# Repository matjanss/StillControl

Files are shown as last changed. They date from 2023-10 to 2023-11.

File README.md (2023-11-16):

# StillControl
Simple Arduino Nano based solid state relay control hardware and software



Repository will be updated intermittently.

Please refer to the "Hardware" folder for the PCB & license information, software folder contains a VSCode project.

https://youtu.be/iHSRMQVA5wc

Watch the video (https://youtu.be/iHSRMQVA5wc)

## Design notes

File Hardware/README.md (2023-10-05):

# StillControl PCB v1.0
Simple Arduino Nano based solid state relay control hardware and software

---

The PCB is a relatively simple breakout board for an Arduino Nano, exposing a number of interfaces in JST PH (2.00mm) connectors and standard 2.54mm pin Headers:

- Footprint for an Arduino Nano V3 with (optional/additional) breakout pin row exposed.
- 3 potentiometers (with filter caps & resistor)
- 3 buffered and somewhat protected SSR outputs
- I2C for ie. display or other peripherals
- I2C header for a BMP388/390 barometer
- 1-Wire interface for temperature sensors
- Buzzer
- Error led connector
- On board 5V regulator, needs 9-12V

WhatsApp Image 2023-10-05 at 22 21 52

Repository will be updated when board is tested, updates to be done in v1.1
Hardware is licensed under Creative Commons NC BY SA.

JLCPCB Production files: StillSSR-Arduinonano.zip

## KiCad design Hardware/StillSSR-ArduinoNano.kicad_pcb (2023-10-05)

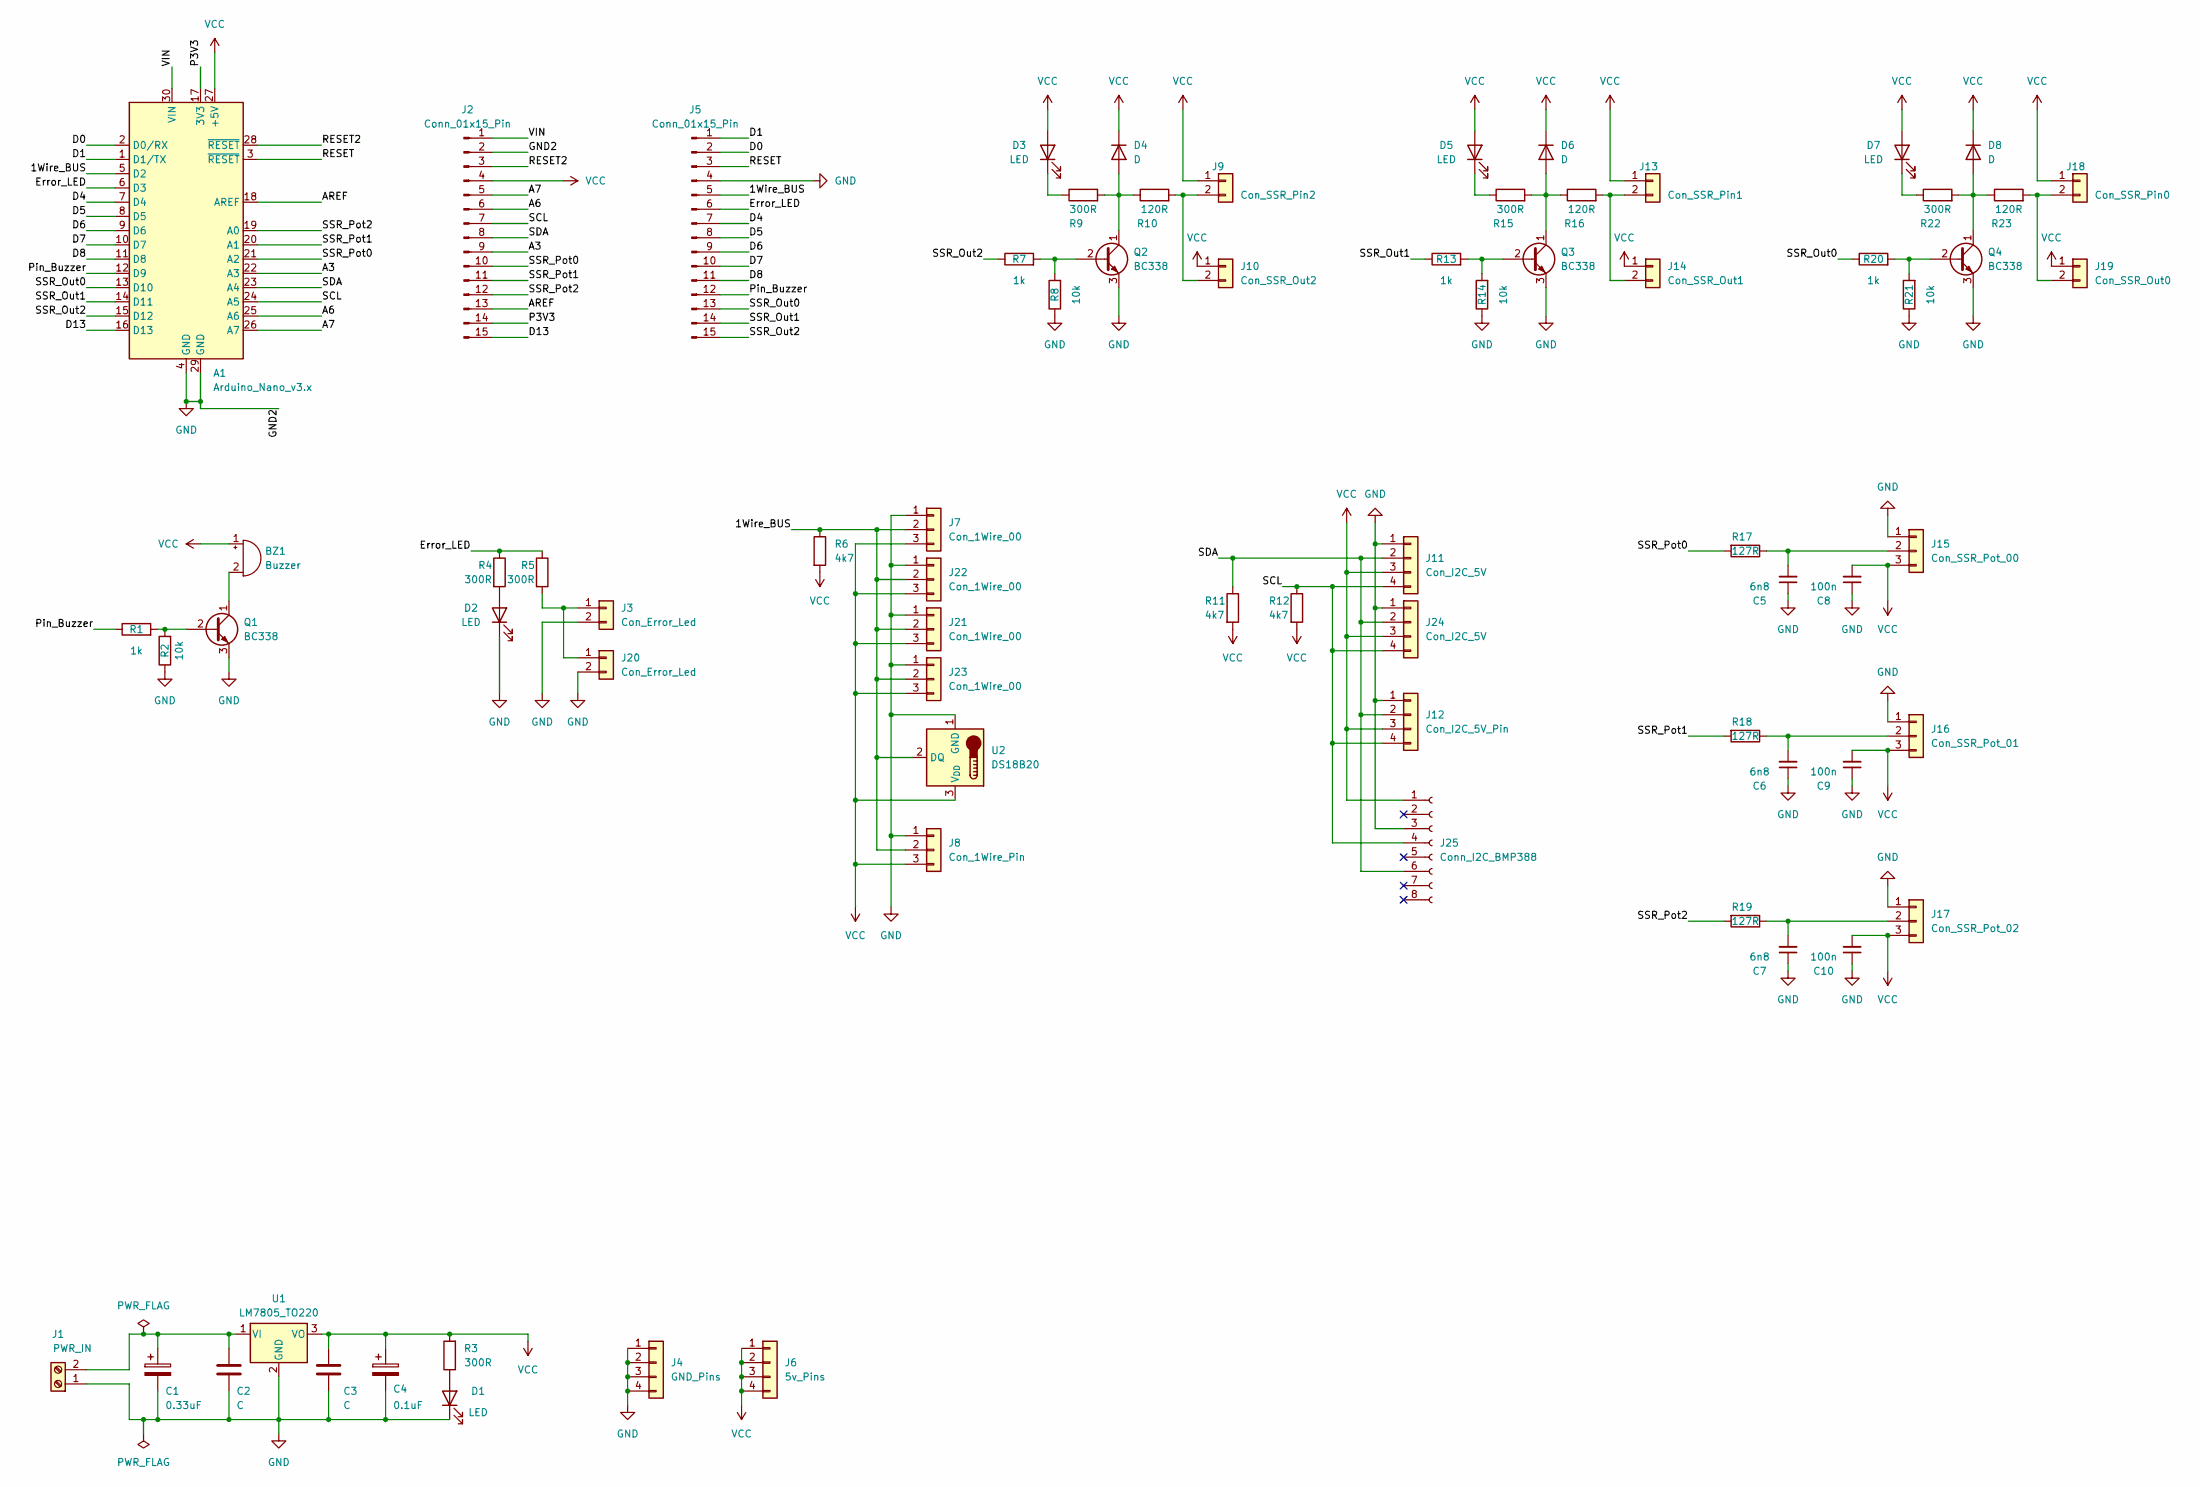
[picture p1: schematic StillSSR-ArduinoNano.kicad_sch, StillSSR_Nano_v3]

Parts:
A1: Arduino_Nano_v3.x; Arduino_Nano
BZ1: Buzzer; Buzzer_12x9.5RM7.6
C1: 0.33uF; CP_Radial_D5.0mm_P2.50mm
C2, C3: C; C_Rect_L4.0mm_W2.5mm_P2.50mm
C4: 0.1uF; CP_Radial_D5.0mm_P2.50mm
C5, C6, C7: 6n8; C_Rect_L4.0mm_W2.5mm_P2.50mm
C8, C9, C10: 100n; C_Rect_L4.0mm_W2.5mm_P2.50mm
D1, D2, D3, D5, D7: LED; LED_D3.0mm
D4, D6, D8: D; D_DO-34_SOD68_P7.62mm_Horizontal
J1: PWR_IN; TerminalBlock_bornier-2_P5.08mm
J2, J5: Conn_01x15_Pin; PinSocket_1x15_P2.54mm_Vertical
J3: Con_Error_Led; JST_PH_B2B-PH-K_1x02_P2.00mm_Vertical
J4: GND_Pins; PinHeader_1x04_P2.54mm_Vertical
J6: 5v_Pins; PinHeader_1x04_P2.54mm_Vertical
J7, J21, J22, J23: Con_1Wire_00; JST_PH_B3B-PH-K_1x03_P2.00mm_Vertical
J8: Con_1Wire_Pin; PinHeader_1x03_P2.54mm_Vertical
J9: Con_SSR_Pin2; PinHeader_1x02_P2.54mm_Vertical
J10: Con_SSR_Out2; JST_PH_B2B-PH-K_1x02_P2.00mm_Vertical
J11, J24: Con_I2C_5V; JST_PH_B4B-PH-K_1x04_P2.00mm_Vertical
J12: Con_I2C_5V_Pin; PinHeader_1x04_P2.54mm_Vertical
J13: Con_SSR_Pin1; PinHeader_1x02_P2.54mm_Vertical
J14: Con_SSR_Out1; JST_PH_B2B-PH-K_1x02_P2.00mm_Vertical
J15: Con_SSR_Pot_00; JST_PH_B3B-PH-K_1x03_P2.00mm_Vertical
J16: Con_SSR_Pot_01; JST_PH_B3B-PH-K_1x03_P2.00mm_Vertical
J17: Con_SSR_Pot_02; JST_PH_B3B-PH-K_1x03_P2.00mm_Vertical
J18: Con_SSR_Pin0; PinHeader_1x02_P2.54mm_Vertical
J19: Con_SSR_Out0; JST_PH_B2B-PH-K_1x02_P2.00mm_Vertical
J20: Con_Error_Led; PinHeader_1x02_P2.54mm_Vertical
J25: Conn_I2C_BMP388; PinSocket_1x08_P2.54mm_Vertical
Q1, Q2, Q3, Q4: BC338; TO-92_Inline
R1, R7, R13, R20: 1k; R_Axial_DIN0207_L6.3mm_D2.5mm_P7.62mm_Horizontal
R2, R8, R14, R21: 10k; R_Axial_DIN0207_L6.3mm_D2.5mm_P7.62mm_Horizontal
R3, R4, R5, R9, R15, R22: 300R; R_Axial_DIN0207_L6.3mm_D2.5mm_P7.62mm_Horizontal
R6, R11, R12: 4k7; R_Axial_DIN0207_L6.3mm_D2.5mm_P7.62mm_Horizontal
R10, R16, R23: 120R; R_Axial_DIN0207_L6.3mm_D2.5mm_P7.62mm_Horizontal
R17, R18, R19: 127R; R_Axial_DIN0207_L6.3mm_D2.5mm_P7.62mm_Horizontal
U1: LM7805_TO220; TO-220-3_Vertical
U2: DS18B20; TO-92_Inline

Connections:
/1Wire_BUS: A1.5 (D2), J5.5, J7.2, J8.2, J21.2, J22.2, J23.2, R6.1, U2.2 (DQ)
/A3: A1.22 (A3), J2.9
/A6: A1.25 (A6), J2.6
/A7: A1.26 (A7), J2.5
/AREF: A1.18 (AREF), J2.13
/D0: A1.2 (D0/RX), J5.2
/D1: A1.1 (D1/TX), J5.1
/D4: A1.7 (D4), J5.7
/D5: A1.8 (D5), J5.8
/D6: A1.9 (D6), J5.9
/D7: A1.10 (D7), J5.10
/D8: A1.11 (D8), J5.11
/D13: A1.16 (D13), J2.15
/Error_LED: A1.6 (D3), J5.6, R4.1, R5.1
/P3V3: A1.17 (3V3), J2.14
/Pin_Buzzer: A1.12 (D9), J5.12, R1.1
/RESET: A1.3 (~RESET), J5.3
/RESET2: A1.28 (~RESET), J2.3
/SCL: A1.24 (A5), J2.7, J11.4, J12.4, J24.4, J25.4, R12.1
/SDA: A1.23 (A4), J2.8, J11.2, J12.2, J24.2, J25.6, R11.1
/SSR_Out0: A1.13 (D10), J5.13, R20.1
/SSR_Out1: A1.14 (D11), J5.14, R13.1
/SSR_Out2: A1.15 (D12), J5.15, R7.1
/SSR_Pot0: A1.21 (A2), J2.10, R17.2
/SSR_Pot1: A1.20 (A1), J2.11, R18.2
/SSR_Pot2: A1.19 (A0), J2.12, R19.2
/VIN: A1.30 (VIN), J2.1
GND: A1.4 (GND), A1.29 (GND), C1.2, C2.2, C3.2, C4.2, C5.1, C6.1, C7.1, C8.1, C9.1, C10.1, D1.1 (K), D2.1 (K), J1.1, J2.2, J3.2, J4.1, J4.2, J4.3, J4.4, J5.4, J7.1, J8.1, J11.1, J12.1, J15.1, J16.1, J17.1, J20.2, J21.1, J22.1, J23.1, J24.1, J25.3, Q1.3 (E), Q2.3 (E), Q3.3 (E), Q4.3 (E), R2.1, R8.1, R14.1, R21.1, U1.2 (GND), U2.1 (GND)
unnamed: BZ1.2 (+), Q1.1 (C)
unnamed: D1.2 (A), R3.1
unnamed: D2.2 (A), R4.2
unnamed: D3.1 (K), R9.1
unnamed: D4.2 (A), Q2.1 (C), R9.2, R10.1
unnamed: D5.1 (K), R15.1
unnamed: D6.2 (A), Q3.1 (C), R15.2, R16.1
unnamed: D7.1 (K), R22.1
unnamed: D8.2 (A), Q4.1 (C), R22.2, R23.1
unnamed: C1.1, C2.1, J1.2, U1.1 (VI)
unnamed: J9.2, J10.2, R10.2
unnamed: J13.2, J14.2, R16.2
unnamed: C5.2, J15.2, R17.1
unnamed: C6.2, J16.2, R18.1
unnamed: C7.2, J17.2, R19.1
unnamed: J18.2, J19.2, R23.2
unnamed: J3.1, J20.1, R5.2
unnamed: Q1.2 (B), R1.2, R2.2
unnamed: Q2.2 (B), R7.2, R8.2
unnamed: Q3.2 (B), R13.2, R14.2
unnamed: Q4.2 (B), R20.2, R21.2
VCC: A1.27 (+5V), BZ1.1 (-), C3.1, C4.1, C8.2, C9.2, C10.2, D3.2 (A), D4.1 (K), D5.2 (A), D6.1 (K), D7.2 (A), D8.1 (K), J2.4, J6.1, J6.2, J6.3, J6.4, J7.3, J8.3, J9.1, J10.1, J11.3, J12.3, J13.1, J14.1, J15.3, J16.3, J17.3, J18.1, J19.1, J21.3, J22.3, J23.3, J24.3, J25.1, R3.2, R6.2, R11.2, R12.2, U1.3 (VO), U2.3 (V_{DD})

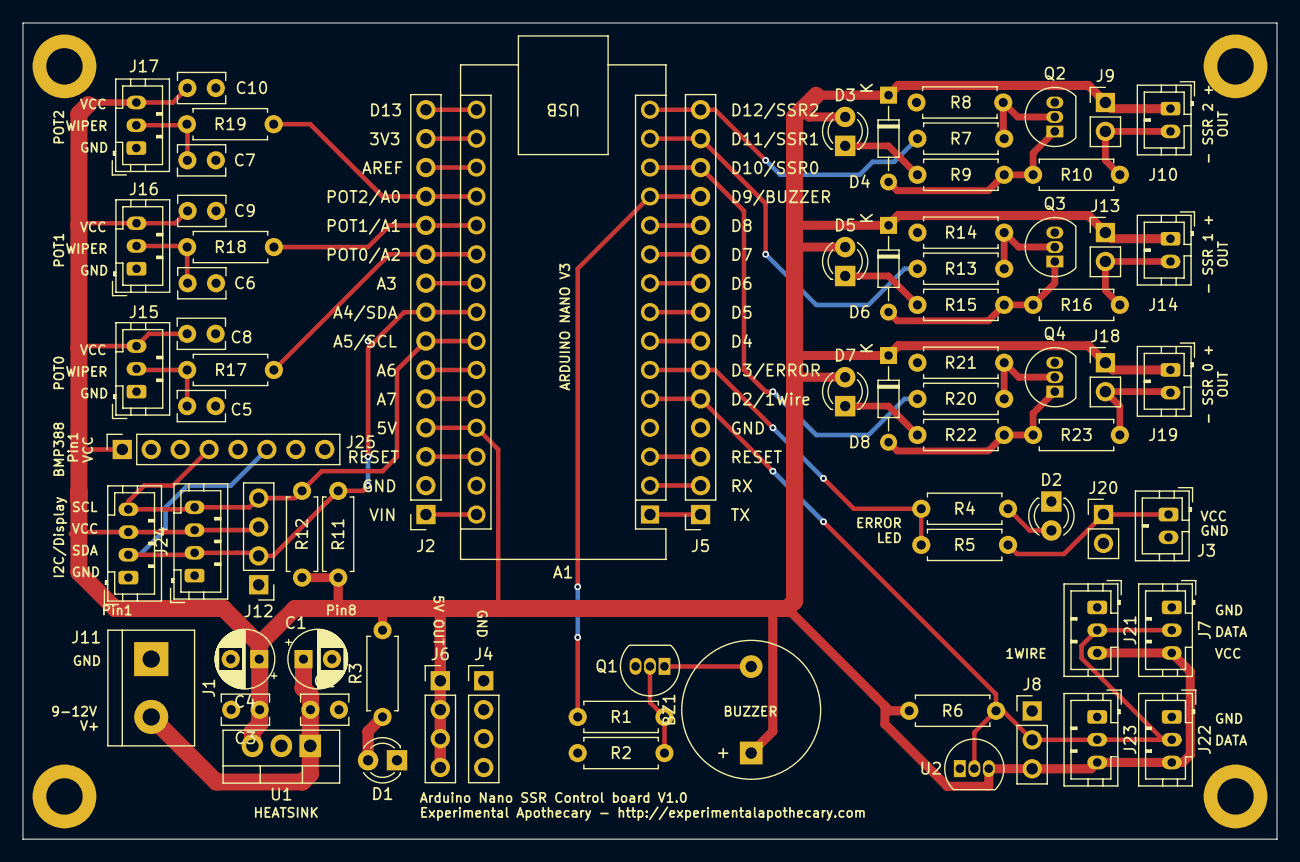
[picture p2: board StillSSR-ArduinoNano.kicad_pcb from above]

Board: 2 copper layers, 110.2 x 71.7 mm, 74 parts (0 on the bottom side), 50 nets.

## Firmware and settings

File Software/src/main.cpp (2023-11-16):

#include <Arduino.h>
#include <EEPROM.h>
#include <ItemProgress.h>
#include <ItemList.h>
#include <ItemCommand.h>
#include <LcdMenu.h>
#include <LiquidCrystal_PCF8574.h>
#include <SimpleRotary.h>
#include <TimerOne.h>
#include <OneWire.h>
#include <DallasTemperature.h>
#include <Wire.h>
#include <DFRobot_BMP3XX.h>
#include <T2ABV.h>

#define USE_ANALOG_POT  // uncomment when using an analog pot for power level setting. rotary encoder will only be used for menu.

#define ROT_PIN_A 4
#define ROT_PIN_B 5
#define ROT_SW 6
#define ONE_WIRE_BUS 2
#define SSR_PIN 10       // timer1 is limited to pins 9 & 10 on UNO and relatives
#define POT_PIN A0       // Analog pot
#define BUZZER_PIN 9
#define ERRORLED_PIN 3

#define LCD_ROWS 4
#define LCD_COLS 20


float tempTop = 0.0;    // temp vapor
float tempStill = 0.0;  // temp Still/wash
float tempProd = 0.0;   // temp of bottom product condensor (= temp of product. -ish)
float tempWater = 0.0;  // temp of cooling water exit
float tempCase = 0.0 ;  // temp of case (from bmp390)
int tempCaseMax = 70;   // max case internal temp (can't change in menu, hardcoded) - could be defined to save ram
float pressure = 0.0;   // atm pressure from bmp390

bool menuActive = false; // keep track of whether the menu is on screen
int dutyCycle = 0;      // holds power level 1-100%
int ssrPeriod = 1;      // ssr PWM period in seconds (NOT Hz)

float vaporABV = 0.0;   //holds vapor abv calc result
float liquidABV = 0.0;  //holds liquid abv calc result


 // function@interval milis timing holders
uint32_t v_UpdateLCD;
uint32_t v_doSetPower;
uint32_t v_doUpdateSensors;
uint32_t v_doClearErrors;

//errors
bool errActive = false;

// Setup rotary encoder with Pin A, Pin B, Button Pin
SimpleRotary rotary(ROT_PIN_A,ROT_PIN_B,ROT_SW);

// eforward declare functions
void callback(uint16_t pos);
void exitMenu();

String action[] = {"None", "Beep", "Shutdown"};

// Define the main menu
MAIN_MENU(
    ITEM_PROGRESS("Warn T Still ", callback),
    ITEM_PROGRESS("Warn T Top   ", callback),
    ITEM_PROGRESS("Warn T Prod  ", callback),
    ITEM_PROGRESS("Warn T Water ", callback),
    ITEM_PROGRESS("Err T Still  ", callback),
    ITEM_PROGRESS("Err T Top    ", callback),
    ITEM_PROGRESS("Err T Prod   ", callback),
    ITEM_PROGRESS("Err T Water  ", callback),
    ITEM_STRING_LIST("Warn Action  ", action, 3, callback),
    ITEM_STRING_LIST("Error Action ", action, 3, callback),
    ITEM_PROGRESS("Still sensor ", callback),
    ITEM_PROGRESS("Top sensor   ", callback),
    ITEM_PROGRESS("Prod sensor  ", callback),
    ITEM_PROGRESS("Water sensor ", callback),
    ITEM_PROGRESS("Calibrt Still", callback),
    ITEM_PROGRESS("Calibrt Top  ", callback)
    //ITEM_COMMAND("Exit / Save", exitMenu) // MAX 16 MENU ITEMS per menu. exit with long click.

);


// Define a struct to save the menu settings to eeprom.
struct mySettings 
{
  int valid, //for checking valid settings
      warnStill,
      warnTop,
      warnProd,
      warnWater,
      errStill,
      errTop,
      errProd,
      errWater,
      warnAction,
      errAction,
      sensorStill,
      sensorTop,
      sensorProd,
      sensorWater,
      calStill,
      calTop;
};
mySettings settings;

LcdMenu menu(LCD_ROWS, LCD_COLS);

OneWire oneWire(ONE_WIRE_BUS);
DallasTemperature sensors(&oneWire);

DFRobot_BMP390L_I2C bmp;

void redrawLCD()
{
  menu.lcd->clear();
  menu.lcd->setCursor(0,0);
  menu.lcd->print(F("Power:"));
  menu.lcd->setCursor(0,2);
  menu.lcd->print(F("Vapor:"));
  menu.lcd->setCursor(0,3);
  menu.lcd->print(F("Wash:"));

  menu.lcd->setCursor(12,0);
  menu.lcd->print(F("WT"));
  menu.lcd->setCursor(12,1);
  menu.lcd->print(F("WB"));
  menu.lcd->setCursor(12,2);
  menu.lcd->print(F(">"));
  menu.lcd->setCursor(12,3);
  menu.lcd->print(F(">"));

}


void exitMenu ()
{
  EEPROM.put(0x0100, settings); // .update won't accept the struct with ints (why??)
  menuActive = false;
  menu.hide();
  redrawLCD();
}

void updateNav()
{
  byte i;

  if(menuActive) // Menu active, use menu controls
  {
      // 0 = not turning, 1 = CW, 2 = CCW
    i = rotary.rotate();

    if ( i == 1 ) {
      //CW = down or right
      if(menu.isInEditMode())
      {
        menu.right();
      }
      else {
        menu.down();
      }
    }

    if ( i == 2 ) {
      //CCW = up or left
      if(menu.isInEditMode())
      {
        menu.left();
      }
      else 
      {
        menu.up();
      }
    }
      // 0 = not pushed, 1 = pushed, 2 = long pushed
    i = rotary.pushType(1000); // number of milliseconds button has to be pushed for it to be considered a long push.

    if ( i == 1 ) {
      if(menu.isInEditMode())
      {
        //send back (confirm input)
        menu.back();
      }
      else 
      {
        //Short click
        menu.enter();
      }
    }
    
    if ( i == 2 ) 
    {
      //long click
      exitMenu();
    }
  } 

  else { // MENU not active, control only power and start menu button

  #ifndef USE_ANALOG_POT  // rotary encoder

    // 0 = not turning, 1 = CW, 2 = CCW
    i = rotary.rotate();

    if ( i == 1 )
    {
      //Clockwise -> powerplus
      if (dutyCycle > 98) 
      {
        dutyCycle = 100;
      } else
      {
        dutyCycle++;
      }
    }

    if ( i == 2 )
    {
      //Counter clockwise -> powermin
      if (dutyCycle < 2) 
      {
        dutyCycle = 0;
      } else 
      {
        dutyCycle--;
      }
    }
  #endif // end rotary encoder power level setting

  #ifdef USE_ANALOG_POT // use analog pot for power level setting only if so instructed

    int potValue = analogRead(POT_PIN);
    dutyCycle = map(potValue, 0, 1023, 0, 100);
    if (dutyCycle < 2) dutyCycle = 0;
    if (dutyCycle > 98 ) dutyCycle = 100;

  #endif

 
    // 0 = not pushed, 1 = pushed, 2 = long pushed
    i = rotary.pushType(1000); // number of milliseconds button has to be pushed for it to be considered a long push.
  
  #ifndef USE_ANALOG_POT
    if (i == 1 ) {
      dutyCycle = 0;
    }
  #endif

    if ( i == 2) 
    { 
      //Button LONG pressed, show menu
      menuActive = true;
      menu.show();
    }

  }
}


void callback(uint16_t value) 
{
  // do something when menu settings are changed
  Serial.print(F("value: "));
  Serial.println(value);
  Serial.print(F("menu: "));
  Serial.println(menu.getCursorPosition());

  switch (menu.getCursorPosition()) 
  {
    case 1:
      settings.warnStill = value;
      break;

    case 2:
      settings.warnTop = value;
      break;
    
    case 3:
      settings.warnProd = value;
      break;

    case 4:
      settings.warnWater = value;
      break;

    case 5:
      settings.errStill = value;
      break;

    case 6:
      settings.errTop = value;
      break;

    case 7:
      settings.errProd = value;
      break;

    case 8:
      settings.errWater = value;
      break;

    case 9:
      settings.warnAction = value;
      break;
    
    case 10:
      settings.errAction = value;
      break;
    
    case 11:
      settings.sensorStill = value;
      break;

    case 12:
      settings.sensorTop = value;
      break;

    case 13:
      settings.sensorProd = value;
      break;

    case 14:
      settings.sensorWater = value;
      break;

    case 15:
      settings.calStill = value;
      break;
    
    case 16:
      settings.calTop = value;
      break;

    default:
      break;
  }

}

//Time the execution of functions
void doFunctionAtInterval(void (*callBackFunction)(), uint32_t &lastEvent, uint32_t Interval) {
  uint32_t now = millis();
  if ((now - lastEvent) >= Interval) 
  {
    lastEvent = now;
    callBackFunction();
  }
}



void doUpdateLCD()
{
  // print power level
  char buf[7];
  if(dutyCycle >0)
  {
    sprintf(buf, "%3d", dutyCycle);
    menu.lcd->setCursor(7,0);
    menu.lcd->print(buf);
    menu.lcd->print(F("%"));
  } else
  {
    menu.lcd->setCursor(7,0);
    menu.lcd->print(F("OFF "));
  }
  
  //print abv TOP
  if (tempTop > 79 )
  {
    dtostrf(vaporABV, 3, 0, buf); 
    menu.lcd->setCursor(7,2);
    menu.lcd->print(buf);
    menu.lcd->print(F("%"));
  } else{
    menu.lcd->setCursor(7,2);
    menu.lcd->print(F("... "));
  }
  // print abv wash
  if (tempStill > 79 )
  {
    dtostrf(liquidABV, 4, 1, buf); 
    menu.lcd->setCursor(6,3);
    menu.lcd->print(buf);
    menu.lcd->print(F("%"));
  } else{
    menu.lcd->setCursor(7,3);
    menu.lcd->print(F("... "));
  }

  // print cooling water exit temp
  dtostrf(tempWater, 6, 1, buf);
  menu.lcd->setCursor(14,0);
  menu.lcd->print(buf);

  // print product/bottom water temp
  dtostrf(tempProd, 6, 1, buf);
  menu.lcd->setCursor(14,1);
  menu.lcd->print(buf);

  // print vapor temp
  dtostrf(tempTop, 6, 1, buf);
  menu.lcd->setCursor(14,2);
  menu.lcd->print(buf);

  // print wash temp
  dtostrf(tempStill, 6, 1, buf);
  menu.lcd->setCursor(14,3);
  menu.lcd->print(buf);

}

void doSetPower()
{
  Timer1.setPwmDuty(SSR_PIN, (float(dutyCycle) / 100) * 1023); // set pwm duty between 0-1023 
}

void doUpdateSensors()
{
  // Tidy this up for multiple sensors
  sensors.requestTemperatures(); // Send the command to get temperatures
  tempTop = sensors.getTempCByIndex(settings.sensorTop) + (float (settings.calTop - 100) / 100);
  tempStill = sensors.getTempCByIndex(settings.sensorStill) + (float (settings.calStill - 100) / 100);
  tempProd = sensors.getTempCByIndex(settings.sensorProd);
  tempWater = sensors.getTempCByIndex(settings.sensorWater);

  //todo - rest of sensors
  tempCase = bmp.readTempC();
  pressure = bmp.readPressPa()/100;

  vaporABV = TtoVaporABV(tempTop, pressure);
  liquidABV = TtoLiquidABV(tempStill, pressure);
}


void setup() 
{
  Serial.begin(9600);
  Serial.println(F("Initializing Menu..."));
  
  menu.setupLcdWithMenu(0x27, mainMenu);
  menu.hide();
  menuActive = false;

  menu.lcd->clear();



  
  // get settings from eeprom
  EEPROM.get(0x0100, settings);
  Serial.println(F("Grabbing settings from EEPROM"));
  if(settings.valid != 2) // if no valid eeprom found, reset defaults. First byte at address 0x0100 should be 2 for validtion reasons
  {
    Serial.println(F("EEPROM not OK, resetting to defaults"));
    settings.valid = 2;
    settings.warnStill = 99;
    settings.warnTop = 99; 
    settings.warnProd = 35;
    settings.warnWater = 65;
    settings.errStill = 102;
    settings.errTop = 101;
    settings.errProd = 45;
    settings.errWater = 80;
    settings.warnAction = 1;
    settings.errAction = 1;
    settings.sensorStill = 1;
    settings.sensorTop = 1;
    settings.sensorProd = 1;
    settings.sensorWater = 1;
    settings.calStill = 100;
    settings.calTop = 100;
    EEPROM.put(0x0100, settings);  //storing struct into EEPROM
  }

  //Serial.println(F("EEPROM seems to be OK"));
  //Serial.println(F("Settings retrieved:"));
  //populate menu defaults from eeprom 
  char buf[5];

  itoa(settings.warnStill, buf, 10 );
  menu[1]->setValue(buf);
  //Serial.print(F("Warn T Still: "));
  //Serial.println(buf);

  itoa(settings.warnTop, buf, 10 );
  menu[2]->setValue(buf);
  //Serial.print(F("Warn T Top: "));
  //Serial.println(buf);

  itoa(settings.warnProd, buf, 10 );
  menu[3]->setValue(buf);
  //Serial.print(F("Warn T Prod: "));
  //Serial.println(buf);

  itoa(settings.warnWater, buf, 10 );
  menu[4]->setValue(buf);
  //Serial.print(F("Warn T Water: "));
  //Serial.println(buf);

  itoa(settings.errStill, buf, 10 );
  menu[5]->setValue(buf);
  //Serial.print(F("Err T Still: "));
  //Serial.println(buf);

  itoa(settings.errTop, buf, 10 );
  menu[6]->setValue(buf);
  //Serial.print(F("Err T Top: "));
  //Serial.println(buf);

  itoa(settings.errProd, buf, 10 );
  menu[7]->setValue(buf);
  //Serial.print(F("Err T Prod: "));
  //Serial.println(buf);

  itoa(settings.errWater, buf, 10 );
  menu[8]->setValue(buf);
  //Serial.print(F("Err T Water: "));
  //Serial.println(buf);

  menu[9]->setItemIndex(settings.warnAction);
  //Serial.print(F("Warn Action: "));
  //Serial.print(settings.warnAction);
  //Serial.print(F(" or "));
  //Serial.println(action[settings.warnAction]);

  menu[10]->setItemIndex(settings.errAction);
  //Serial.print(F("Err Action: "));
  //Serial.print(settings.errAction);
  //Serial.print(F(" or "));
  //Serial.println(action[settings.errAction]);  

  itoa(settings.sensorStill, buf, 10 );
  menu[11]->setValue(buf);
  //Serial.print(F("Sensor Still: "));
  //Serial.println(buf);

  itoa(settings.sensorTop, buf, 10 );
  menu[12]->setValue(buf);
  //Serial.print(F("Sensor Top: "));
  //Serial.println(buf);

  itoa(settings.sensorProd, buf, 10 );
  menu[13]->setValue(buf);
  //Serial.print(F("Sensor Prod: "));
  //Serial.println(buf);

  itoa(settings.sensorWater, buf, 10 );
  menu[14]->setValue(buf);
  //Serial.print(F("Sensor Water: "));
  //Serial.println(buf);

  itoa(settings.calStill, buf, 10 );
  menu[15]->setValue(buf);
  //Serial.print(F("Calibrate still: "));
  //Serial.println(buf);

  itoa(settings.calTop, buf, 10 );
  menu[16]->setValue(buf);
  //Serial.print(F("calibrate Water: "));
  //Serial.println(buf);

  menu.update();
  
  

  // Init SSR pwm timer
  pinMode(SSR_PIN, OUTPUT); 
  Timer1.initialize( ssrPeriod * 1000000);                // period * 1000000 is period in seconds -> microseconds
  Timer1.pwm(SSR_PIN, 0 );  // start flipflopping on pin A with dutycycle ssrDutyCycle (initially 0, so off)
  Serial.println(F("Timer1 is switching, duty cycle set to 0% ..."));

  // start 1wire and DS18B20
  sensors.begin();
  sensors.setWaitForConversion(false);      // make it async, don't wait for the reading (we'll get it the next second)
  sensors.setResolution(12);                // set max resolution
  Serial.println(F("Started DS18B20 sensors ..."));

  // temporary, for the rotary encoder power. need to put connector on pcb
  pinMode(7, OUTPUT);
  digitalWrite(7, HIGH);

  bmp.begin();
  bmp.setSamplingMode(bmp.eUltraPrecision);
  /*bmp.setPWRMode(bmp.ePressEN |        // enable pressure reading
                    bmp.eTempEN |      // enable temp reading
                    bmp.eForcedMode);  // power mode "forced" 
*/
  bmp.setOSRMode(bmp.ePressOSRMode32 | // 32x oversampling pressure reading
                    bmp.eTempOSRMode1);// 2x oversampling temp reading
  bmp.setODRMode(BMP3XX_ODR_1P5_HZ);      // 1.5Hz data rate
  bmp.setIIRMode(BMP3XX_IIR_CONFIG_COEF_127); // set IIR coefficient for accuracy; 

  // Give everything some time to settele
  Serial.println(F("Stabilizing subsystems... :) "));
  delay (5000);

  Serial.println(F("Starting Loop ..."));
  redrawLCD();
}

void doHandleErrors(int errorType, char *errorMessage) //type 1 = warn, type 2 = error
{
  Serial.println(F("Error triggered:"));
  Serial.print(F("Type: "));
  Serial.println(errorType);
  Serial.print(F("Message:"));
  Serial.println(errorMessage);

  int i = 0;
  errActive = true; // set error active = true, prevent from giving an error direct after clearing it.
  v_doClearErrors = millis(); // reset counter to start from NOW

    if ( errorType == 1 ) 
    {
      switch (settings.warnAction)
      {
        case 0: // do nothing
          break;
        
        case 1: // BEEP
          Serial.println(F("Handling Type 1 error - warning"));
          // put notice on LCD
          menu.lcd->clear();
          menu.lcd->setCursor(0,1);
          menu.lcd->print(errorMessage);
          // Beeep
          tone(BUZZER_PIN, 2000, 500);
          delay(1000); //ouch!
          tone(BUZZER_PIN, 2000, 500);
          // Wait for input
          
          while (i == 0)
          {
            i = rotary.push();
          }
          redrawLCD();
          // error was handled:
          break;
        
        case 2: // SHUTDOWN
        Serial.println(F("Handling Type 1 error - Shutdown"));
          // shutdown still
          dutyCycle = 0;
          doSetPower();
          // put notice on LCD
          menu.lcd->clear();
          menu.lcd->setCursor(0,1);
          menu.lcd->print(errorMessage);
          menu.lcd->setCursor(0,2);
          menu.lcd->print(F("  Still Shut Down"));
          // Beeep
          tone(BUZZER_PIN, 2000, 500);
          delay(1000); //ouch!
          tone(BUZZER_PIN, 2000, 500);
          // Wait for input
          
          while (i == 0)
          {
            i = rotary.push();
          }
          redrawLCD();
          // error was handled:
          break;
      }
    }

    if ( errorType == 2 ) 
    {
      switch (settings.errAction)
      {
        case 0: // do nothing
          break;
        
        case 1: // BEEP
          Serial.println(F("Handling Type 2 error - ERROR"));
          // put notice on LCD
          menu.lcd->clear();
          menu.lcd->setCursor(0,1);
          menu.lcd->print(errorMessage);
          // Beeep
          tone(BUZZER_PIN, 2000, 500);
          delay(1000); //ouch!
          tone(BUZZER_PIN, 2000, 500);
          // Wait for input
          
          while (i == 0)
          {
            i = rotary.push();
          }
          redrawLCD();
          // error was handled:
          break;
        
        case 2: // SHUTDOWN
        Serial.println(F("Handling Type 2 error - Shutdown"));
          // shutdown still
          dutyCycle = 0;
          doSetPower();
          // put notice on LCD
          menu.lcd->clear();
          menu.lcd->setCursor(0,1);
          menu.lcd->print(errorMessage);
          menu.lcd->setCursor(0,2);
          menu.lcd->print(F("  Still Shut Down"));
          // Beeep
          tone(BUZZER_PIN, 2000, 500);
          delay(1000); //ouch!
          tone(BUZZER_PIN, 2000, 500);
          // Wait for input
          
          while (i == 0)
          {
            i = rotary.push();
          }
          redrawLCD();
          // error was handled:
          break;
      }
    }
  

}

void doCheckErrors()
{

  if( tempTop > settings.warnTop )    { char msg[20] = "Vapor Temp Warning!";  doHandleErrors(1, msg ); }
  if( tempStill > settings.warnStill ){ char msg[20] = " Wash Temp Warning!";  doHandleErrors(1, msg ); }
  if( tempWater > settings.warnWater ){ char msg[20] = "Water Temp Warning!";  doHandleErrors(1, msg ); }
  if( tempProd > settings.warnProd )  { char msg[20] = "Water Temp Warning!";  doHandleErrors(1, msg ); }

  if( tempTop > settings.errTop )     { char msg[20] = "  Vapor Temp Error!";  doHandleErrors(2, msg ); }
  if( tempStill > settings.errStill ) { char msg[20] = "  Wash Temp Error!";   doHandleErrors(2, msg ); }
  if( tempWater > settings.errWater)  { char msg[20] = " Water Temp Error!";   doHandleErrors(2, msg ); }
  if( tempProd > settings.errProd )   { char msg[20] = "Product Temp Error!";  doHandleErrors(2, msg ); }

  if( tempCase > tempCaseMax )        { char msg[20] = "Control Temp Error!";  doHandleErrors(2, msg); }
}

void doClearErrors()
{
  errActive = false;
}


void loop() 
{
  updateNav(); //check rotary button for actions, read analog pot if any
  
  if(!menuActive) 
  {
    doFunctionAtInterval(doUpdateLCD, v_UpdateLCD, 100);
    doFunctionAtInterval(doSetPower, v_doSetPower, 1000);
    doFunctionAtInterval(doUpdateSensors, v_doUpdateSensors, 1000);
    doFunctionAtInterval(doClearErrors, v_doClearErrors, 120000); // clear errors for 2 minutes
    
    if(!errActive) doCheckErrors(); // only throw an error if erractive has been cleared

  }

}

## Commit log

2023-10-05 Add files via upload
    Upload v1.0 of JLCPCB gerber files
2023-10-05 Kicad schematics added
    [StillSSR-ArduinoNano.kicad_pcb, StillSSR-ArduinoNano.kicad_sch]

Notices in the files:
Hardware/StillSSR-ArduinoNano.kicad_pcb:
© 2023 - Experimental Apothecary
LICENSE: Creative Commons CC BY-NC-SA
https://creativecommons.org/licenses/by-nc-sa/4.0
